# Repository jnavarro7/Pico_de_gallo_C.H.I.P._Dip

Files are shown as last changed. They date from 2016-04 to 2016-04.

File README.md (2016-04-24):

# CHIP_Relay_Dip
Relay Dip for the C.H.I.P. Single board computer  
It is a 2 channel relay board  
Has a DC/DC converter(5V, 1.5A) and an AC jack(2.1mm) to provide power to the Dip and C.H.I.P(Via the CHG-IN pin) boards   
Uses optocouplers to protect the pins and the C.H.I.P(To activate them it needs to sink 5mA)

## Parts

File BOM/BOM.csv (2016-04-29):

RefDes | Name | Value | Pattern | Manufacturer | Quantity | Datasheet
3pin5mm1 | 1935174 | 3pin5mm | 3pin5mm | Phoenix Contact | 1
3pin5mm2 | 1935174 | 3pin5mm | 3pin5mm | Phoenix Contact | 1
C1 | CAP_0805 | 4.7uF | CAP_0805 |  | 1
C2 | CAP_0805 | 47uF | CAP_0805 |  | 1
D1 | DIODE | 1N4001 | DO-35 |  | 1
F1 | FUSE F1206A2R00FWTR\500 |  | RES_1206 | AVX | 1
J1 | PJ-002B |  | PJ-002B | CUI | 1
K1 | G5LE-14-DC5 |  | G5LE | Omron | 1
K2 | G5LE-14-DC5 |  | G5LE | Omron | 1
LED1 | SML-LXT0805IW-TR |  | DIO_0805 | Lumex | 1
LED2 | SML-LXT0805IW-TR |  | DIO_0805 | Lumex | 1
OC1 | VO617A |  | DIP-4 | Vishay Semiconductors | 1
OC2 | VO617A |  | DIP-4 | Vishay Semiconductors | 1
Q1 | 2N2222 |  | TO-18 | Central Semiconductor | 1
Q2 | 2N2222 |  | TO-18 | Central Semiconductor | 1
R1 | RES_0805 | 390 ohm | RES_0805 |  | 1
R2 | RES_0805 | 180 ohm | RES_0805 |  | 1
R3 | RES_0805 | 390 ohm | RES_0805 |  | 1
R4 | RES_0805 | 180 ohm | RES_0805 |  | 1
U1 | chip_dip_2 | 2x20_header | HDR-2x20 |  | 1
U2 | MMBD4148 |  | MMBD4148 | Fairchild Semiconductor | 1
U3 | MMBD4148 |  | MMBD4148 | Fairchild Semiconductor | 1
U4 | chip_dip | 2x20_header | HDR-2x20 |  | 1
U5 | OKI-78SR-5/1.5-W36H-C |  | OKI-78SR-5/1.5-W36H-C |  | 1

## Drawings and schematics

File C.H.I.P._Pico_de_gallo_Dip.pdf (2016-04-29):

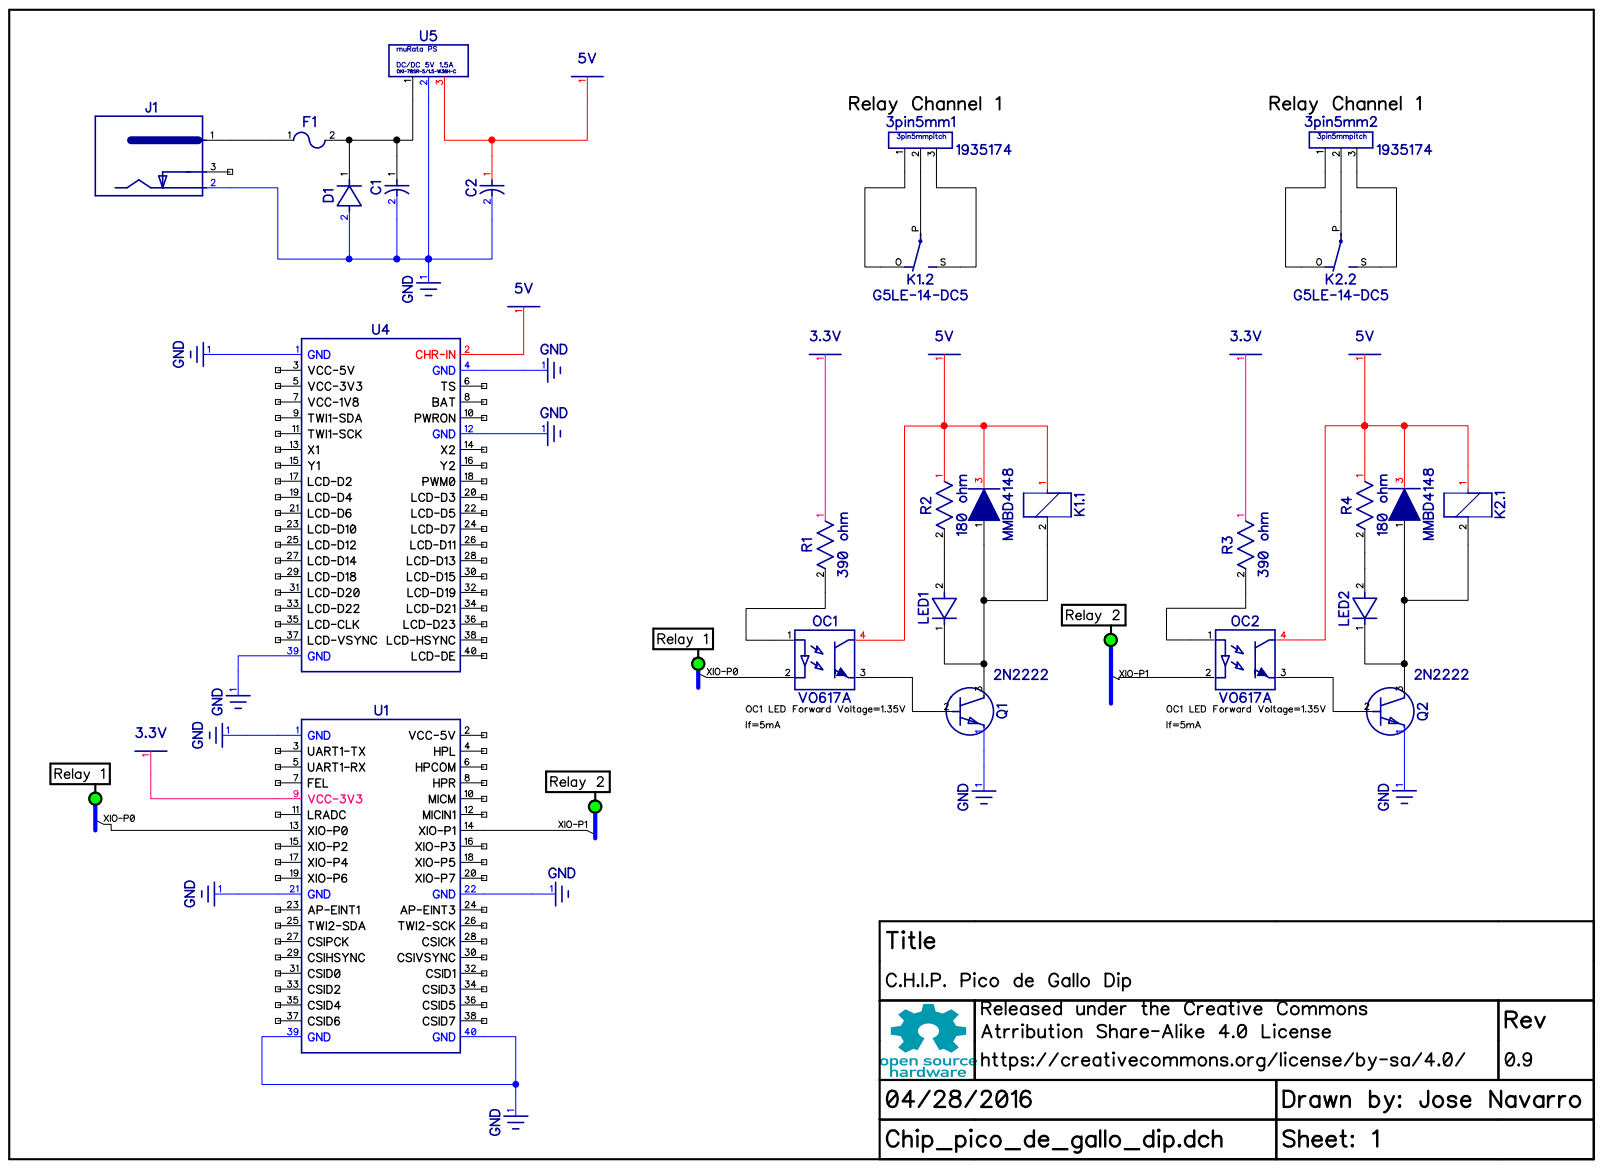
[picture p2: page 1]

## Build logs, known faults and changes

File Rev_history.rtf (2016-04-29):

Revision history:

0.8
Initial release

0.9
Added reverse polarity protection diode to the Dip power supply.

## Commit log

2016-04-24 File renaming
    File renaming to contain the “Pico de Gallo” name
2016-04-25 Updates and added Gerber files
    Updates to the design and added Gerber files.
    [BoardOutline.gbr, Bottom.gbr, BottomAssy.gbr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]
2016-04-29 Bump to Rev 0.9
    Bumped to revision 0.9(schematic and layout), added reverse polarity
    protection diode, updated pdf schematic, gerber files and added BOM
    [BOM.csv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]
2016-05-28 Update
    Updated power jack holes to support OSH Park manufacturing.
    [BoardOutline.gbr, Bottom.gbr, BottomAssy.gbr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]
